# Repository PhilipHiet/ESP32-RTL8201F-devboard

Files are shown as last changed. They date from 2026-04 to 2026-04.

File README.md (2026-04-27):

# ESP32-RTL8201F-devboard
A simple ESP32 devboard with WiFi and Ethernet using the RTL8201F transceiver including an onboard USB-C-port for power, programming and serial console.

## Design
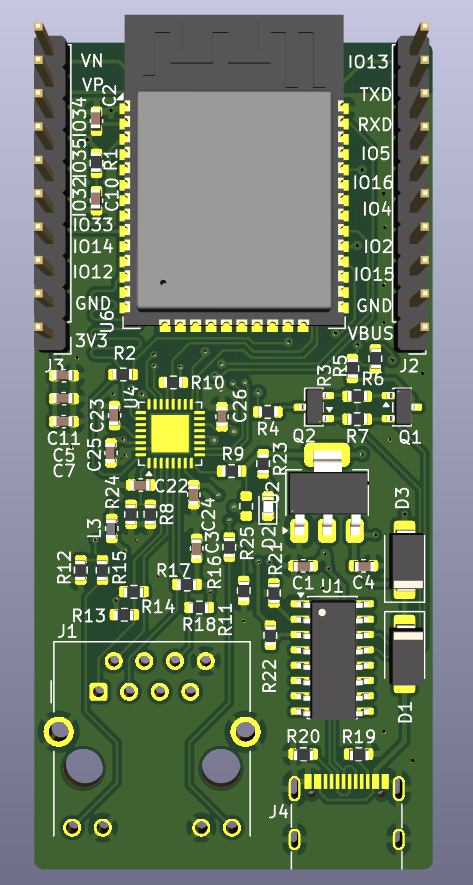
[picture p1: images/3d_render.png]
3d render


The schematics are based on the [esp-32-poe-dev project by @jorticus](https://github.com/jorticus/esp32-poe-dev) but using the ESP32-WROOM-32E module instead of a barebone ESP32.

This board is designed as a 4-layer PCB and is optimized for cheap assembly with JLCPCB. So using basic parts where possible and a custom ESP32-WROOM-32E footrpint so the minimum via-hole-size is 0.3mm.

## Assembly
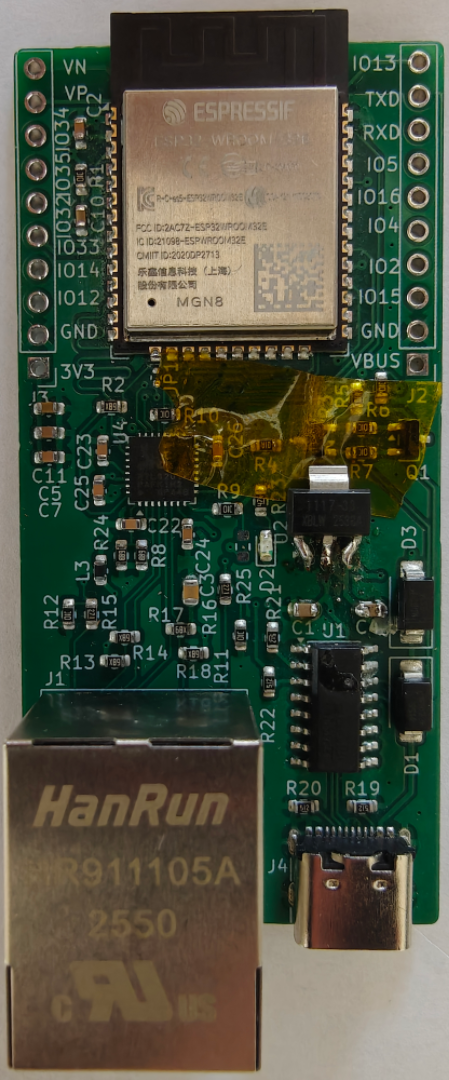
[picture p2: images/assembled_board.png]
assebled board


The boards were fully assembled by JLCPCB (except for the pinheaders).
The necessary production files are included under pcb/jilcpcb.

In the first interation I chose the wrong 3.3V LDO and had to amnually swap those. The uploaded board- and assembly-files are already fixed.

## Development using platform.io
Save the [esp32-rtl8201f-devboard.json](esp32-rtl8201f-devboard.json) into the `boards` directory of your platform.io project. Creating the folder if it doesn't exist yet.

Select the board in your `platformio.ini`
```ini
[env:esp32dev]
monitor_speed=115200
platform = espressif32
board = esp32-rtl8201f-devboard
framework = arduino
```
Now you can `#include <ETH.h>` and call `ETH.begin();` in your code.
Check out the [firmware-examples](firmware-examples) for more details.

## Stability
The main goal was to have a more stable link than the onboard wifi and with packet-loss around .00003% in my test I think it's pretty stable.

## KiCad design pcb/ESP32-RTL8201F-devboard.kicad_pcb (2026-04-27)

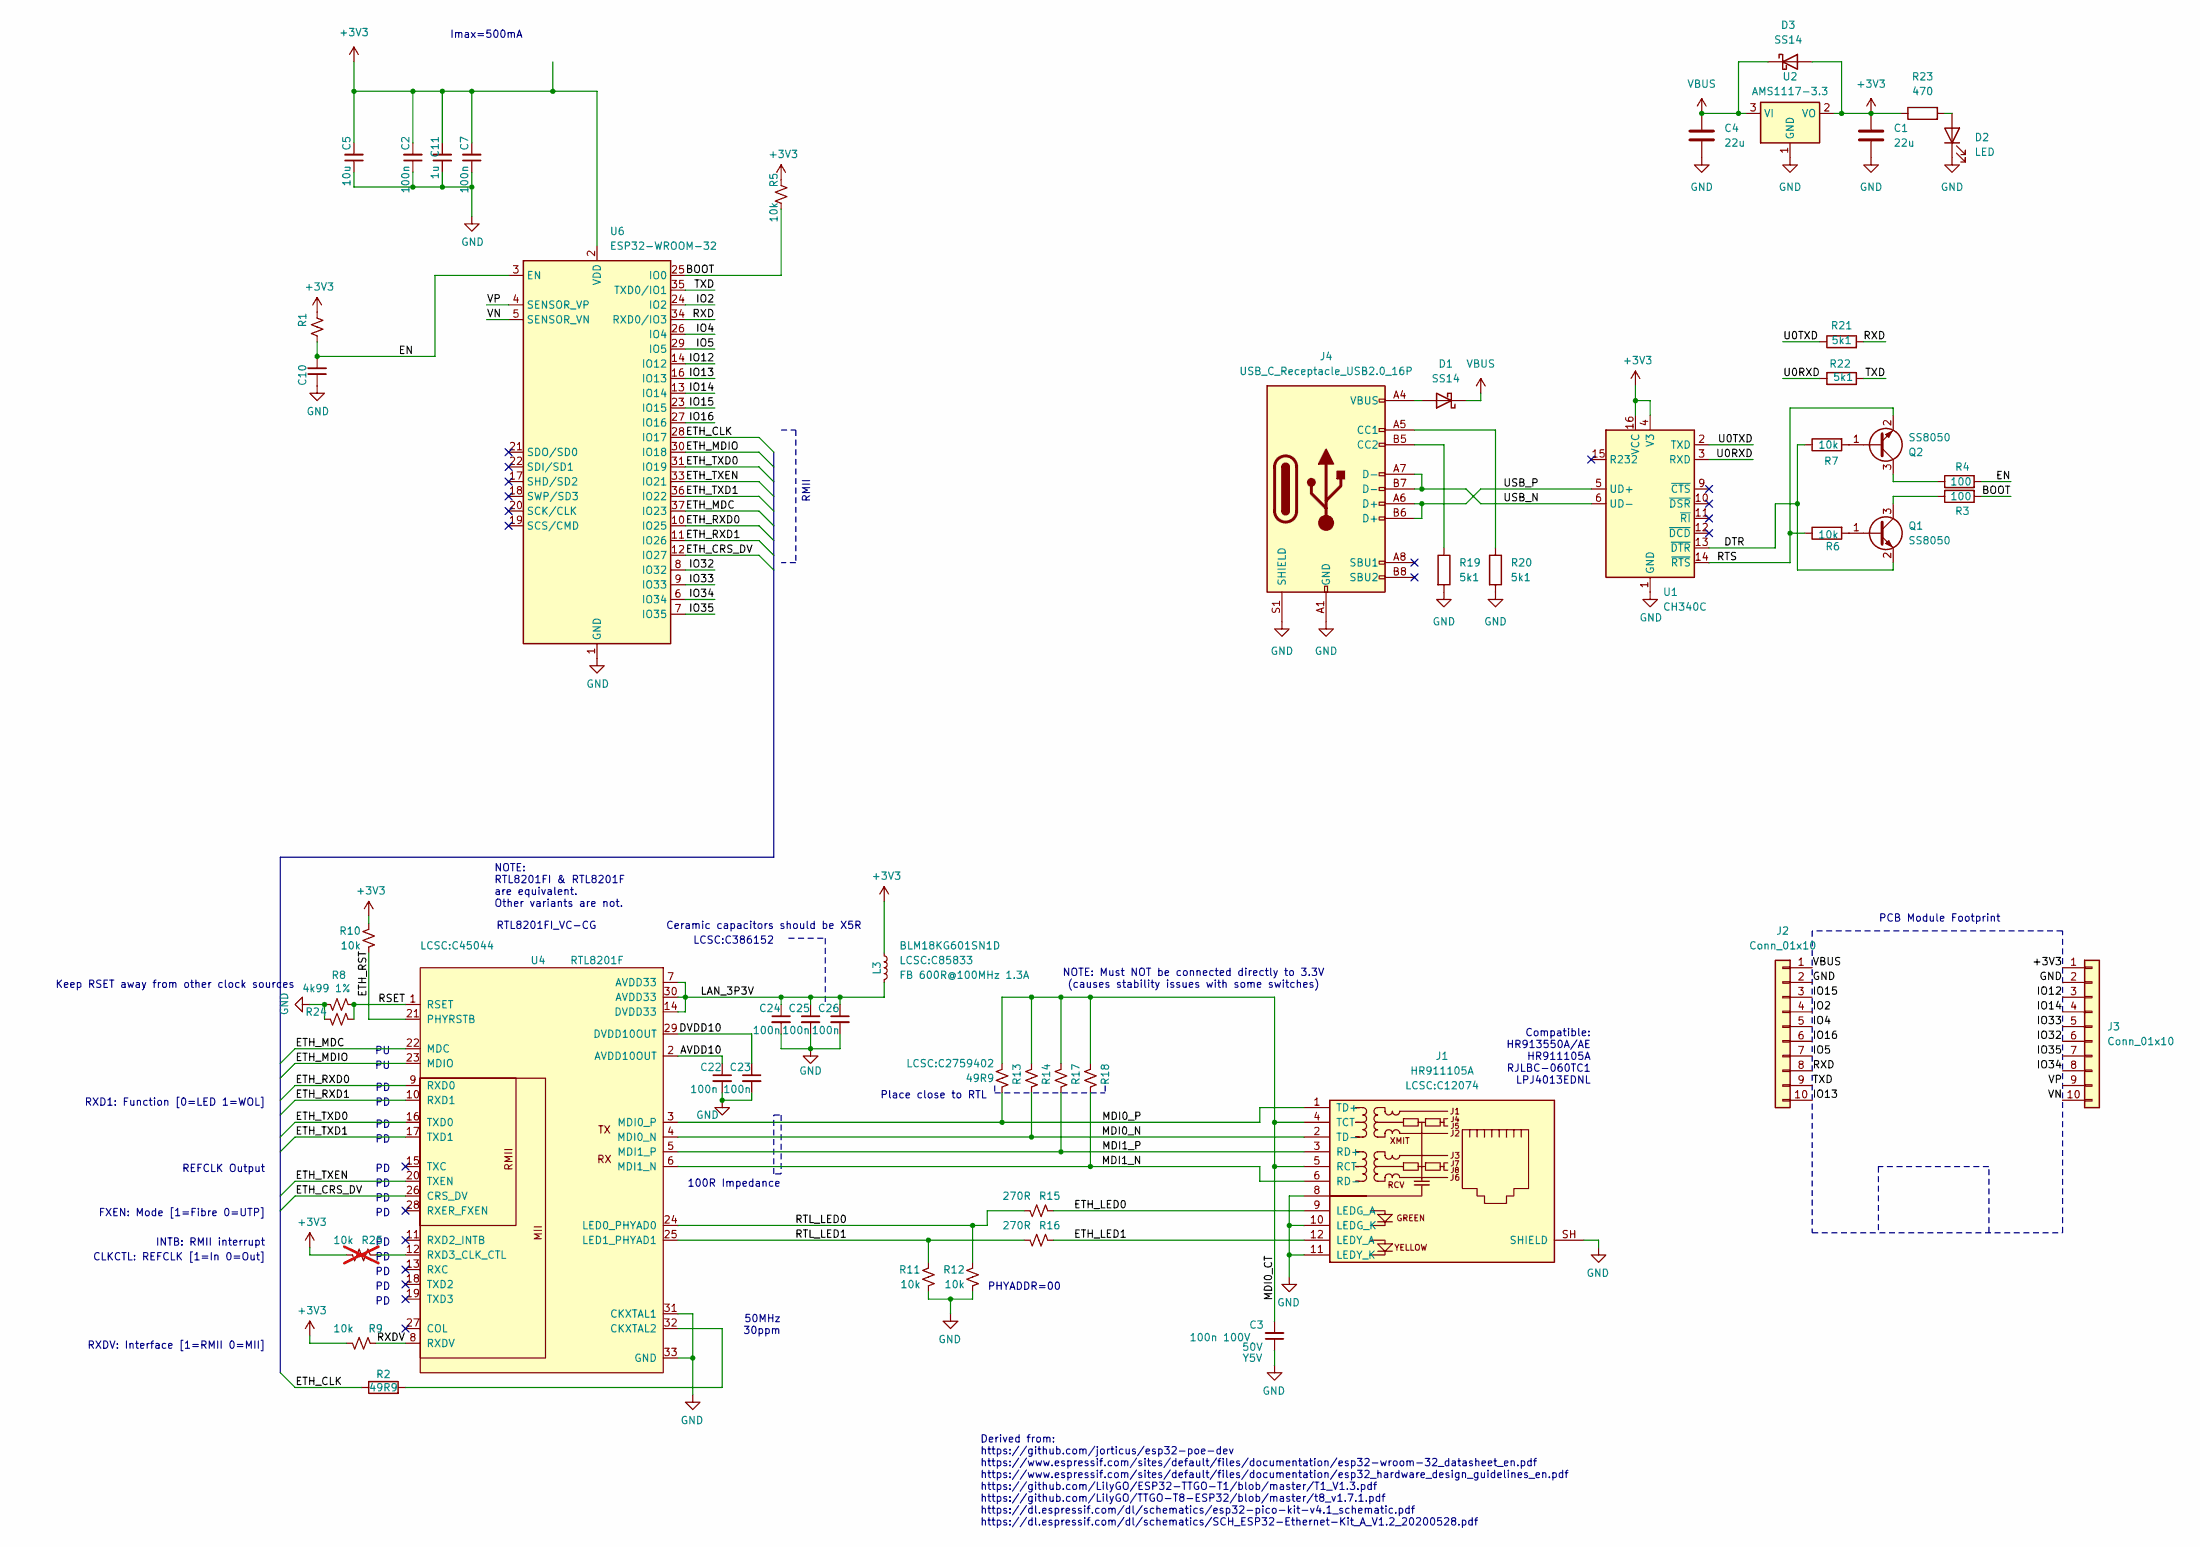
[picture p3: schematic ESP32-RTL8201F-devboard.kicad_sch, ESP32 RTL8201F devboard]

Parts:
C1, C4: 22u; C_0603_1608Metric; LCSC part number C59461
C2, C7, C22, C23, C24, C25, C26: 100n; C_0603_1608Metric; LCSC part number C14663
C3: 100n 100V; C_0603_1608Metric; Rating 50V; LCSC part number C28233
C5: 10u; C_0603_1608Metric; LCSC part number C19702
C10, C11: 1u; C_0603_1608Metric; LCSC part number C15849
D1, D3: SS14; D_SMA; LCSC part number C2480
D2: LED; LED_0603_1608Metric; LCSC part number C2286
J1: HR911105A; RJ45_Hanrun_HR911105A_Horizontal; Part LCSC:C12074; LCSC part number C12074
J2, J3: Conn_01x10; PinHeader_1x10_P2.54mm_Vertical
J4: USB_C_Receptacle_USB2.0_16P; USB_C_Receptacle_G-Switch_GT-USB-7010ASV; LCSC part number C393939
L3: FB 600R@100MHz 1.3A; L_0603_1608Metric; Part1 LCSC:C85833; LCSC part number C85833
Q1, Q2: SS8050; SOT-23; LCSC part number C2150
R1, R5, R6, R7, R9, R10, R11, R12: 10k; R_0603_1608Metric; LCSC part number C25804
R2: 49R9; R_0603_1608Metric; LCSC part number C23185
R3, R4: 100; R_0603_1608Metric; LCSC part number C22775
R8, R24: 4k99 1%; R_0603_1608Metric; LCSC part number C23046
R13: 49R9; R_0603_1608Metric; Part LCSC:C2759402; LCSC part number C23185
R14, R17, R18: 49.9R 1%; R_0603_1608Metric; LCSC part number C23185
R15, R16: 270R; R_0603_1608Metric; LCSC part number C22966
R19, R20, R21, R22: 5k1; R_0603_1608Metric; LCSC part number C23186
R23: 470; R_0603_1608Metric; LCSC part number C23179
R25: 10k; R_0603_1608Metric; LCSC part number C25804; not fitted
U1: CH340C; SOIC-16_3.9x9.9mm_P1.27mm; LCSC part number C84681
U2: AMS1117-3.3; SOT-223-3_TabPin2; LCSC part number C6186
U4: RTL8201F; QFN-32-1EP_5x5mm_P0.5mm_EP3.1x3.1mm; Part2 LCSC:C45044; LCSC part number C45044
U6: ESP32-WROOM-32; ESP32-WROOM-32E; LCSC part number C701342

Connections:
+3V3: C1.1, C2.2, C5.2, C7.2, C11.2, D3.2 (A), J3.1, L3.1, R1.2, R5.2, R9.1, R10.1, R23.1, R25.1, U1.4 (V3), U1.16 (VCC), U2.2 (VO), U6.2 (VDD)
/AVDD10: C22.1, U4.2 (AVDD10OUT)
/BOOT: R3.2, R5.1, U6.25 (IO0)
/DTR: Q1.2 (E), R7.1, U1.13 (~DTR)
/DVDD10: C23.1, U4.29 (DVDD10OUT)
/EN: C10.2, R1.1, R4.2, U6.3 (EN)
/ETH_CLK: R2.1, U6.28 (IO17)
/ETH_CRS_DV: U4.26 (CRS_DV), U6.12 (IO27)
/ETH_LED0: J1.9 (LEDG_A), R15.2
/ETH_LED1: J1.12 (LEDY_A), R16.2
/ETH_MDC: U4.22 (MDC), U6.37 (IO23)
/ETH_MDIO: U4.23 (MDIO), U6.30 (IO18)
/ETH_RST: R10.2, U4.21 (PHYRSTB)
/ETH_RXD0: U4.9 (RXD0), U6.10 (IO25)
/ETH_RXD1: U4.10 (RXD1), U6.11 (IO26)
/ETH_TXD0: U4.16 (TXD0), U6.31 (IO19)
/ETH_TXD1: U4.17 (TXD1), U6.36 (IO22)
/ETH_TXEN: U4.20 (TXEN), U6.33 (IO21)
/IO2: J2.4, U6.24 (IO2)
/IO4: J2.5, U6.26 (IO4)
/IO5: J2.7, U6.29 (IO5)
/IO12: J3.3, U6.14 (IO12)
/IO13: J2.10, U6.16 (IO13)
/IO14: J3.4, U6.13 (IO14)
/IO15: J2.3, U6.23 (IO15)
/IO16: J2.6, U6.27 (IO16)
/IO32: J3.6, U6.8 (IO32)
/IO33: J3.5, U6.9 (IO33)
/IO34: J3.8, U6.6 (IO34)
/IO35: J3.7, U6.7 (IO35)
/LAN_3P3V: C24.1, C25.1, C26.1, L3.2, U4.7 (AVDD33), U4.14 (DVDD33), U4.30 (AVDD33)
/MDI0_CT: C3.2, J1.4 (TCT), J1.5 (RCT), R13.1, R14.1, R17.1, R18.1
/MDI0_N: J1.2 (TD-), R14.2, U4.4 (MDI0_N)
/MDI0_P: J1.1 (TD+), R13.2, U4.3 (MDI0_P)
/MDI1_N: J1.6 (RD-), R18.2, U4.6 (MDI1_N)
/MDI1_P: J1.3 (RD+), R17.2, U4.5 (MDI1_P)
/RSET: R8.2, R24.2, U4.1 (RSET)
/RTL_LED0: R12.1, R15.1, U4.24 (LED0_PHYAD0)
/RTL_LED1: R11.1, R16.1, U4.25 (LED1_PHYAD1)
/RTS: Q2.2 (E), R6.1, U1.14 (~RTS)
/RXD: J2.8, R21.2, U6.34 (RXD0/IO3)
/RXDV: R9.2, U4.8 (RXDV)
/TXD: J2.9, R22.2, U6.35 (TXD0/IO1)
/U0RXD: R22.1, U1.3 (RXD)
/U0TXD: R21.1, U1.2 (TXD)
/USB_N: J4.A7 (D-), J4.B7 (D-), U1.6 (UD-)
/USB_P: J4.A6 (D+), J4.B6 (D+), U1.5 (UD+)
/VN: J3.10, U6.5 (SENSOR_VN)
/VP: J3.9, U6.4 (SENSOR_VP)
GND: C1.2, C2.1, C3.1, C4.2, C5.1, C7.1, C10.1, C11.1, C22.2, C23.2, C24.2, C25.2, C26.2, D2.1 (K), J1.8, J1.10 (LEDG_K), J1.11 (LEDY_K), J1.SH (SHIELD), J2.2, J3.2, J4.A1 (GND), J4.A12 (GND), J4.B1 (GND), J4.B12 (GND), J4.S1 (SHIELD), R8.1, R11.2, R12.2, R19.2, R20.2, R24.1, U1.1 (GND), U2.1 (GND), U4.31 (CKXTAL1), U4.33 (GND), U6.1 (GND), U6.15 (GND), U6.38 (GND), U6.39 (GND)
unnamed: D1.2 (A), J4.A4 (VBUS), J4.A9 (VBUS), J4.B4 (VBUS), J4.B9 (VBUS)
unnamed: D2.2 (A), R23.2
unnamed: J4.A5 (CC1), R20.1
unnamed: J4.B5 (CC2), R19.1
unnamed: Q1.1 (B), R6.2
unnamed: Q1.3 (C), R3.1
unnamed: Q2.1 (B), R7.2
unnamed: Q2.3 (C), R4.1
unnamed: R2.2, U4.32 (CKXTAL2)
unnamed: R25.2, U4.12 (RXD3_CLK_CTL)
VBUS: C4.1, D1.1 (K), D3.1 (K), J2.1, U2.3 (VI)

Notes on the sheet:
NOTE: Must NOT be connected directly to 3.3V (causes stability issues with some switches)
50MHz 30ppm
Keep RSET away from other clock sources
Derived from: https://github.com/jorticus/esp32-poe-dev https://www.espressif.com/sites/default/files/documentation/esp32-wroom-32_datasheet_en.pdf https://www.espressif.com/sites/default/files/documentation/esp32_hardware_design_guidelines_en.pdf https://github.com/LilyGO/ESP32-TTGO-T1/blob/master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
LCSC:C386152
Compatible: HR913550A/AE HR911105A RJLBC-060TC1 LPJ4013EDNL
Ceramic capacitors should be X5R
PCB Module Footprint
RXD1: Function [0=LED 1=WOL]
INTB: RMII interrupt
NOTE: RTL8201FI & RTL8201F are equivalent. Other variants are not.
RTL8201FI_VC-CG
PHYADDR=00
Imax=500mA
RXDV: Interface [1=RMII 0=MII]
REFCLK Output
100R Impedance
RMII
CLKCTL: REFCLK [1=In 0=Out]
FXEN: Mode [1=Fibre 0=UTP]
Place close to RTL

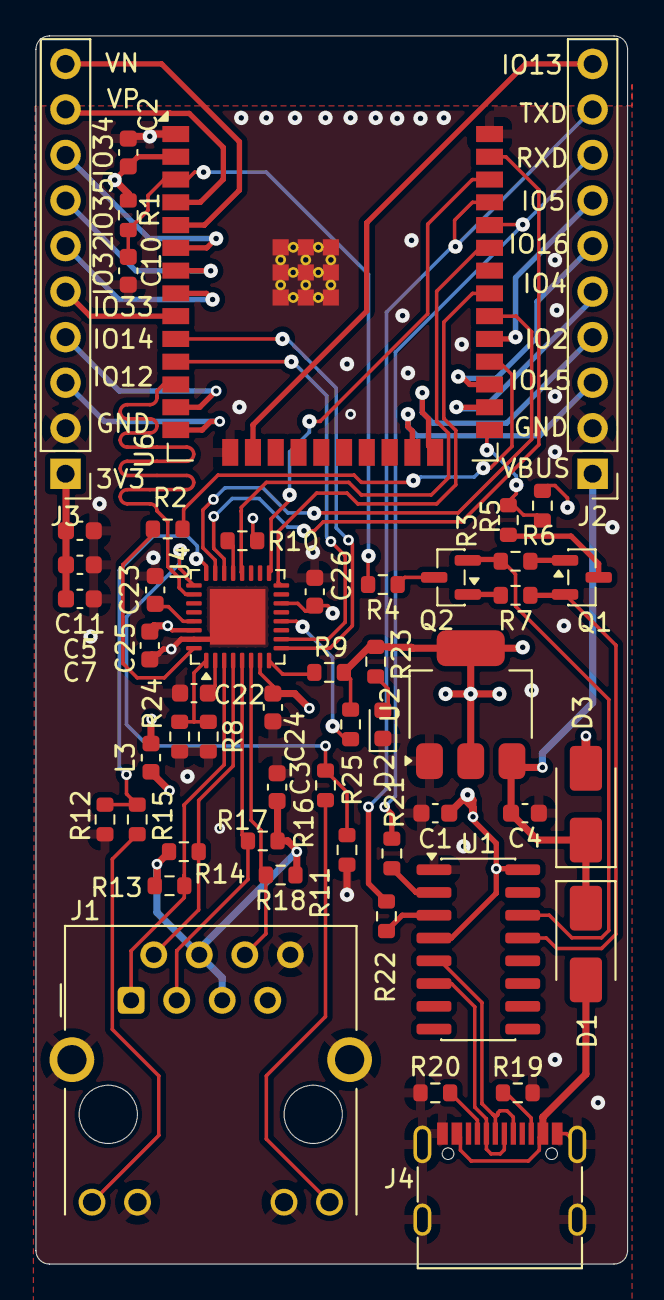
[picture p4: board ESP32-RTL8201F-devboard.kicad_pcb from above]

Board: 4 copper layers, 33.0 x 68.5 mm, 52 parts (0 on the bottom side), 61 nets.

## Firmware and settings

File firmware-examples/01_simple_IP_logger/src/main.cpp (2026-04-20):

#include <Arduino.h>
#include <ETH.h>
#include <WiFi.h>

void setup() {
    Serial.begin(CONFIG_MONITOR_BAUD);
    WiFi.mode(WIFI_OFF);

    ETH.begin();
    ETH.enableIpV6();
}
void loop() {
    if (ETH.linkUp()) {
        Serial.println("ETH link up");
        Serial.print("Speed:");
        Serial.println(ETH.linkSpeed());
        Serial.print("IP:");
        Serial.print(ETH.localIP());
        Serial.print("    ");
        Serial.println(ETH.localIPv6());
    } else {
        Serial.println("ETH link down");
    }
    delay(1000);
}
